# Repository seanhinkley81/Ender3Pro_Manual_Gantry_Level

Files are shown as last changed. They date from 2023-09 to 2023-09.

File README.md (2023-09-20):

# Ender3Pro_Manual_Gantry_Level
Manual Mechanical Gantry level For Ender 3 Pro running klipper

My sagging x gantry has always been causing me problems and I've been getting tired of leveling it. So I got a dual z stepper kit! I have a Cr-Touch but didn't want to get a new 5 driver main board to take advantage of Klipper-s Z stepper auto-alignment or Marlins (G34). So I was looking for solutions with just my stock Creality 4.2.2 board. I saw projects for other setups utilizing newer drivers such as the UART tmc2209 but they take advantage of lower the motor current, which can not be done on the 4.2.2 board. 

I remembered Prusa printers just use a forced mechanical alignment (now depreciated M915 command in Marlin) so wrote up my own gcode script, printed some mechanical endstops and now have a near perfect level x gantry every time. I found it easiest to have the wheels run into the hard stop rather than the gantry itself just due to space constraints and to prevent the bowden tube from being pulled out or pinched by the frame (ask me how i know). But once I had everythign working I could actually see the gantry level itself! (Video coming soon).

Use at your own risk, there always a chance that you can over heat or stress your motors if used excessivly or if you push too long / hard fast ect. I tried to balance speed with "saftey" so that running a Gantry Level (G34) and Bed Mesh (G29) would take less than 3 minutes total - not a bad timeframe to relevel a Ender 3 series. The gantry level should not have to be run very often, only really if the print get stuck or banged and the gantry alignment is knocked off. But having the printer auto-level the gantry instead of breakign out the blocks, leveling, homing ect - is definatly convient.

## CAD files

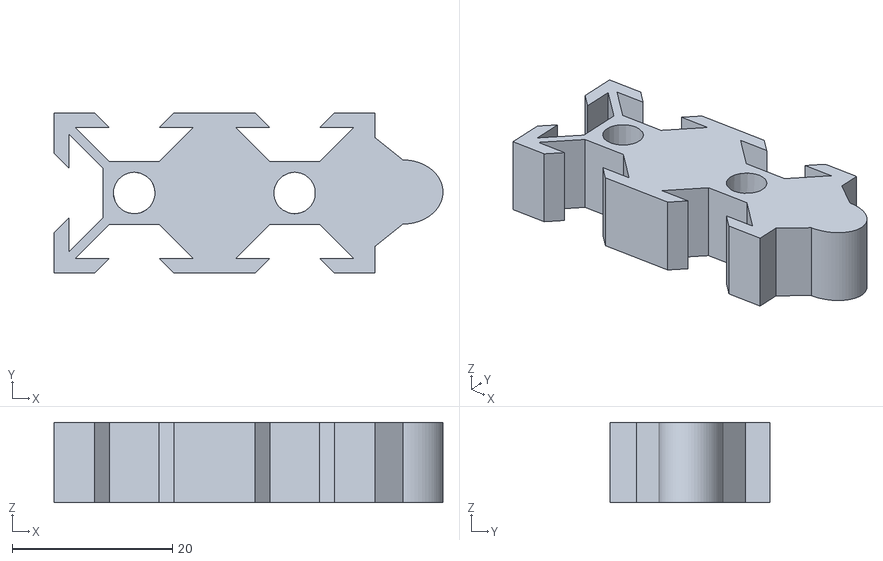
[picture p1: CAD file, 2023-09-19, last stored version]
Gantry Level Stop.stl
48.5 x 20.0 x 10.0

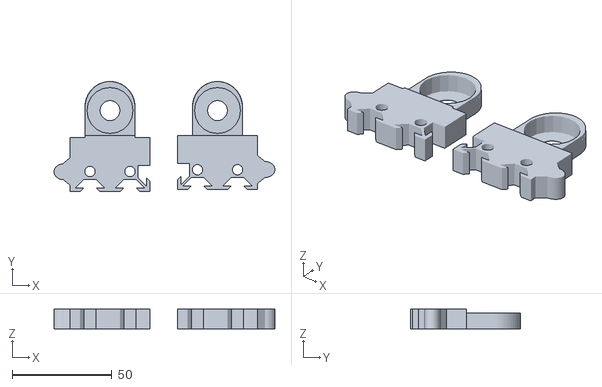
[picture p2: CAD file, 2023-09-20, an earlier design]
Gantry Level Stop (2).stl
110.5 x 55.0 x 10.00

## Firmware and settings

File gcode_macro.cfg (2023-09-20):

[gcode_macro MECHANICAL_GANTRY_CALIBRATION]
gcode:

G28 ; Home all axes

G0 Z250 ; Go to Z Top Max

M211 S0 ; Disable Software Endstops

G91 ; Relative Positioning

G0 Z10 ; Move up 10 mm to push into mechanical endstops and align stepper steps

G0 Z-10 ; Move down 10 mm

G0 Z10 ; Repeat Move up 10 mm to push into mechanical endstops and align stepper steps

G0 Z-10 ; Move down 10 mm

G90 ; Absolute Positioning

M211 S1 ; Enable Software Endstops

G28 ; Home all axes

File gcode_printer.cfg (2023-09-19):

### Gcode for Printer.cfg
## Sean Hinkley
## USE AT YOUR OWN RISK

[gcode_macro G34]
gcode:
    MECHANICAL_GANTRY_CALIBRATION


    [force_move]
enable_force_move: true ;

[menu __main __setup __calib __mech_gantry_calibrate]
type: command
enable: {not printer.idle_timeout.state == "Printing"}
name: G34 Gantry Level
gcode:
    G34

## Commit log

2023-09-19 Create gcode_macro.cfg
    gcode to add to macro.cfg
    [gcode_macro.cfg]
2023-09-19 Create gcode_printer.cfg
    gcode and menu entry for printer.cfg
    [gcode_printer.cfg]
2023-09-19 Add files via upload
    gantry Level stops for top of frame
    [Gantry Level Stop.stl]
